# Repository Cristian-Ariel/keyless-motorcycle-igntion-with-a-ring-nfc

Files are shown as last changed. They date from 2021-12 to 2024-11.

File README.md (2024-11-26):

# Keyless Motorcycle Ignition System with a Ring (NFC)
IMAGE ALT TEXT (https://youtu.be/Ip3jwV7dnoM)

The purpose of the system is to enable the ignition of a motorcycle without the use of a physical key, by utilizing an NFC tag (Near Field Communication). A few key features of the system include:
- Zero current consumption when the motorcycle is off, preventing battery discharge.
- The ability to store up to 128 different tags in memory, which are used as keys.
- Access to "Modes" such as Save/Delete Tag Mode and Erase All Tags Mode to prevent unauthorized use.
- A modular hardware design for prototyping and upgrades to accommodate different motorcycle makes and models.

## How do I build one?
Please watch the video on [Youtube](https://youtu.be/Ip3jwV7dnoM) or [Odysee](https://odysee.com/@AsyssComplex:1/keyless.motorcycle.ignition.with.ring:4?r=8kbGTNhCZ6iqTXnwzbdhoQCgzBPm1UvK).
Lastly, make sure to read [the documentation](https://drive.google.com/file/d/1D22VbdVqOc0YWlI75PouFQuNAUfmh6G7/view?usp=sharing). There you will find the materials and tools to build the system as well as several sections where we discuss the working principles of the system more in detail. The rest of the files, code, PCB files, 3D files are located in this repository.

## How do I contribute?
In the second page of the documentation, there is a brief description of how you can do it. Since the whole system is an ongoing project, I will edit this page and the description of the videos for future updates. Don't forget that you can also share your thoughts on the comment section of the videos.

If you find this project useful and would like to support it, you can buy something (shirts, cups, stickers, etc.) on [this store](https://asyss-complex.creator-spring.com) or you can make a donation on [paypal](https://www.paypal.com/paypalme/Cristi4nAriel).

## Enjoy!

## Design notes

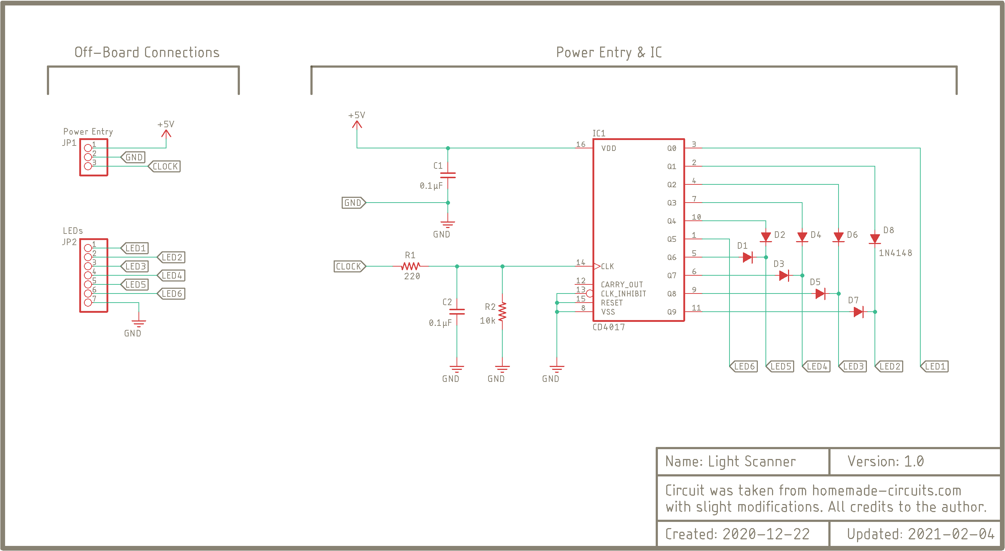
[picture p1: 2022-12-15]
schematic and pcb/light scanner/Light Scanner Capture v1.0.png

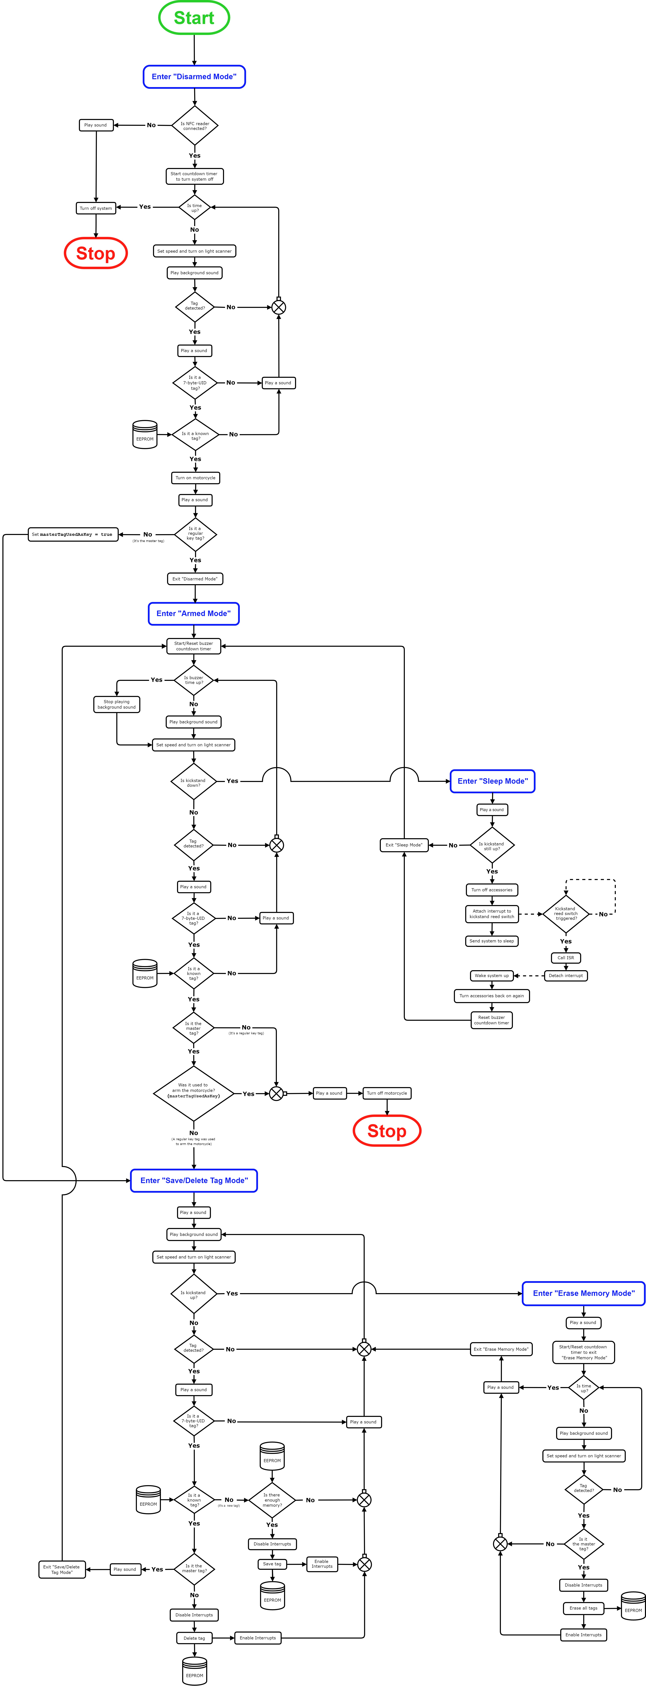
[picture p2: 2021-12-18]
flow chart/flow chart image.jpg

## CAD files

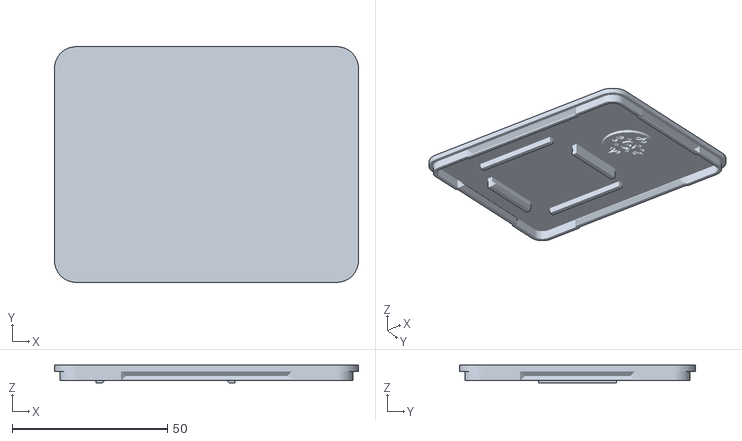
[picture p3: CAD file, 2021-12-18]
3d files/stl files/main enclosure lid.stl
98.0 x 76.0 x 5.70

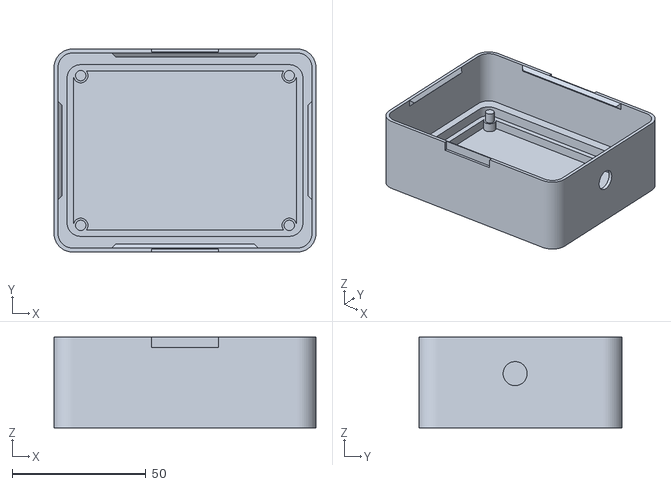
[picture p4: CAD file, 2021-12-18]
3d files/stl files/main enclosure case.stl
98.0 x 76.0 x 34.0

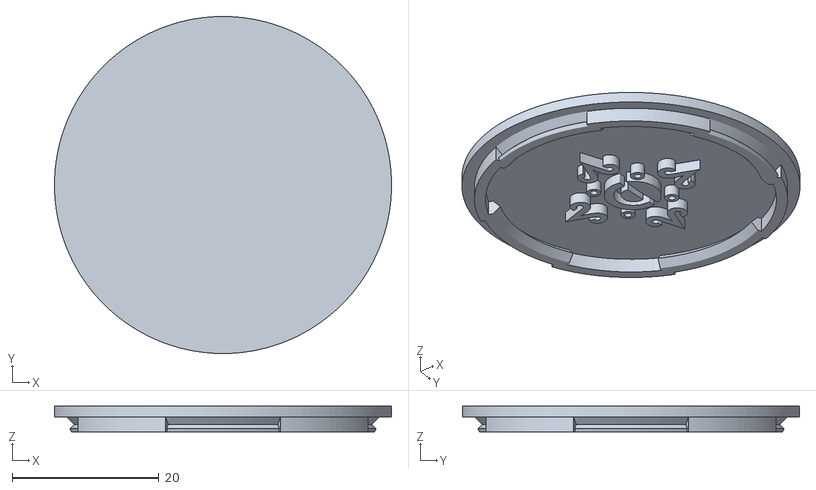
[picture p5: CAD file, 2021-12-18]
3d files/stl files/circular lid.stl
46.0 x 46.0 x 3.50

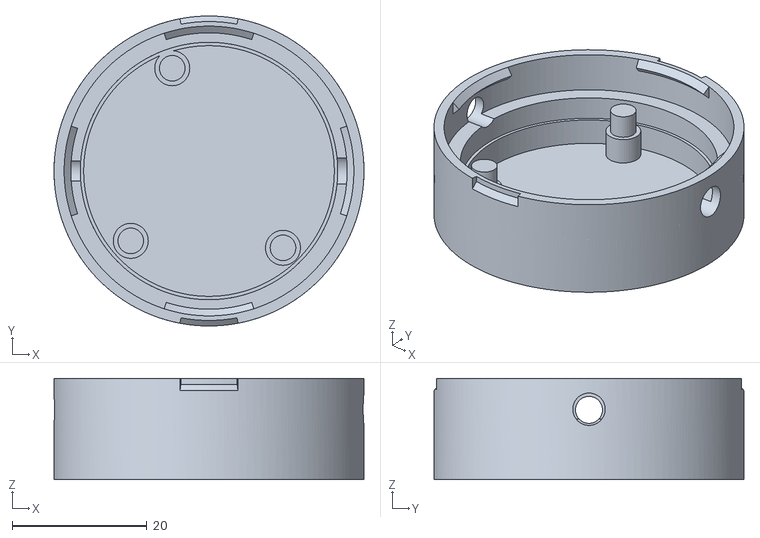
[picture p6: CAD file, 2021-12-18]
3d files/stl files/circular case.stl
46.0 x 46.0 x 15.0

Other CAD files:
3d files/fusion 360 files/circular enclosure v1.0.f3d
3d files/fusion 360 files/main enclosure v1.0.f3d

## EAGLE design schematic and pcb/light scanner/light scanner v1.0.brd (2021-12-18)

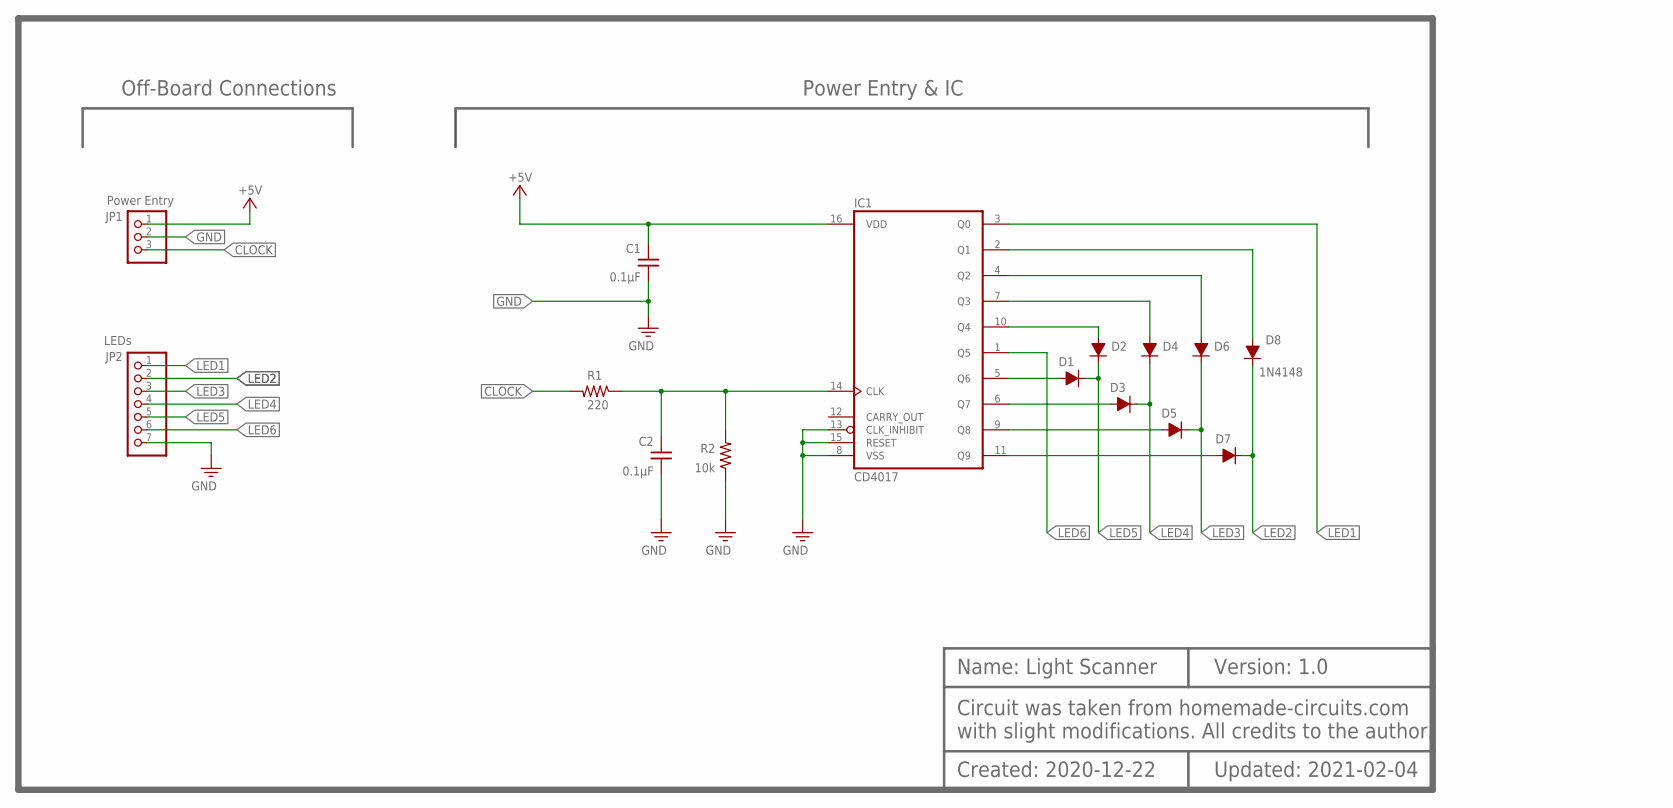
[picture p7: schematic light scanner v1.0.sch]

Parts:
C1, C2: 0.1µF; C_H5
D1, D2, D3, D4, D5, D6, D7: D_1N4148; DO35-7A
D8: 1N4148; DO35-7A
IC1: CD4017; DIP16
JP1: Power Entry; 1X03
JP2: LEDs; 1X07
R1: 220; R_THM
R2: 10k; R_THM

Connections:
+5V: C1.1, IC1.16 (VDD), JP1.1
CLOCK: JP1.3, R1.2
GND: C1.2, C2.2, IC1.8 (VSS), IC1.13 (CLK_INHIBIT), IC1.15 (RESET), JP1.2, JP2.7, R2.1
LED1: IC1.3 (Q0), JP2.1
LED2: D7.C, D8.C, JP2.2
LED3: D5.C, D6.C, JP2.3
LED4: D3.C, D4.C, JP2.4
LED5: D1.C, D2.C, JP2.5
LED6: IC1.1 (Q5), JP2.6
unnamed: C2.1, IC1.14 (CLK), R1.1, R2.2
unnamed: D1.A, IC1.5 (Q6)
unnamed: D2.A, IC1.10 (Q4)
unnamed: D3.A, IC1.6 (Q7)
unnamed: D4.A, IC1.7 (Q3)
unnamed: D5.A, IC1.9 (Q8)
unnamed: D6.A, IC1.4 (Q2)
unnamed: D7.A, IC1.11 (Q9)
unnamed: D8.A, IC1.2 (Q1)

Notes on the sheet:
Power Entry & IC
Off-Board Connections
Name: Light Scanner
Circuit was taken from homemade-circuits.com with slight modifications. All credits to the author.
Created: 2020-12-22
Updated: 2021-02-04
Version: 1.0

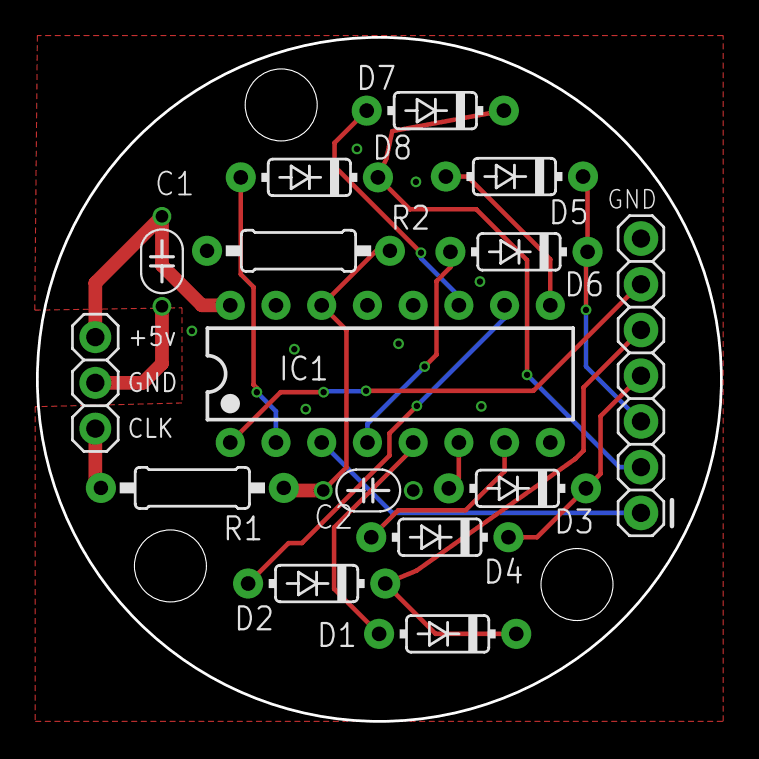
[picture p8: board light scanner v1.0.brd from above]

Board: 2 copper layers, 38.0 x 38.0 mm, 16 parts (1 on the bottom side), 18 nets.

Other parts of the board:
U$2: ASSYS_COMP_LOGO_V6

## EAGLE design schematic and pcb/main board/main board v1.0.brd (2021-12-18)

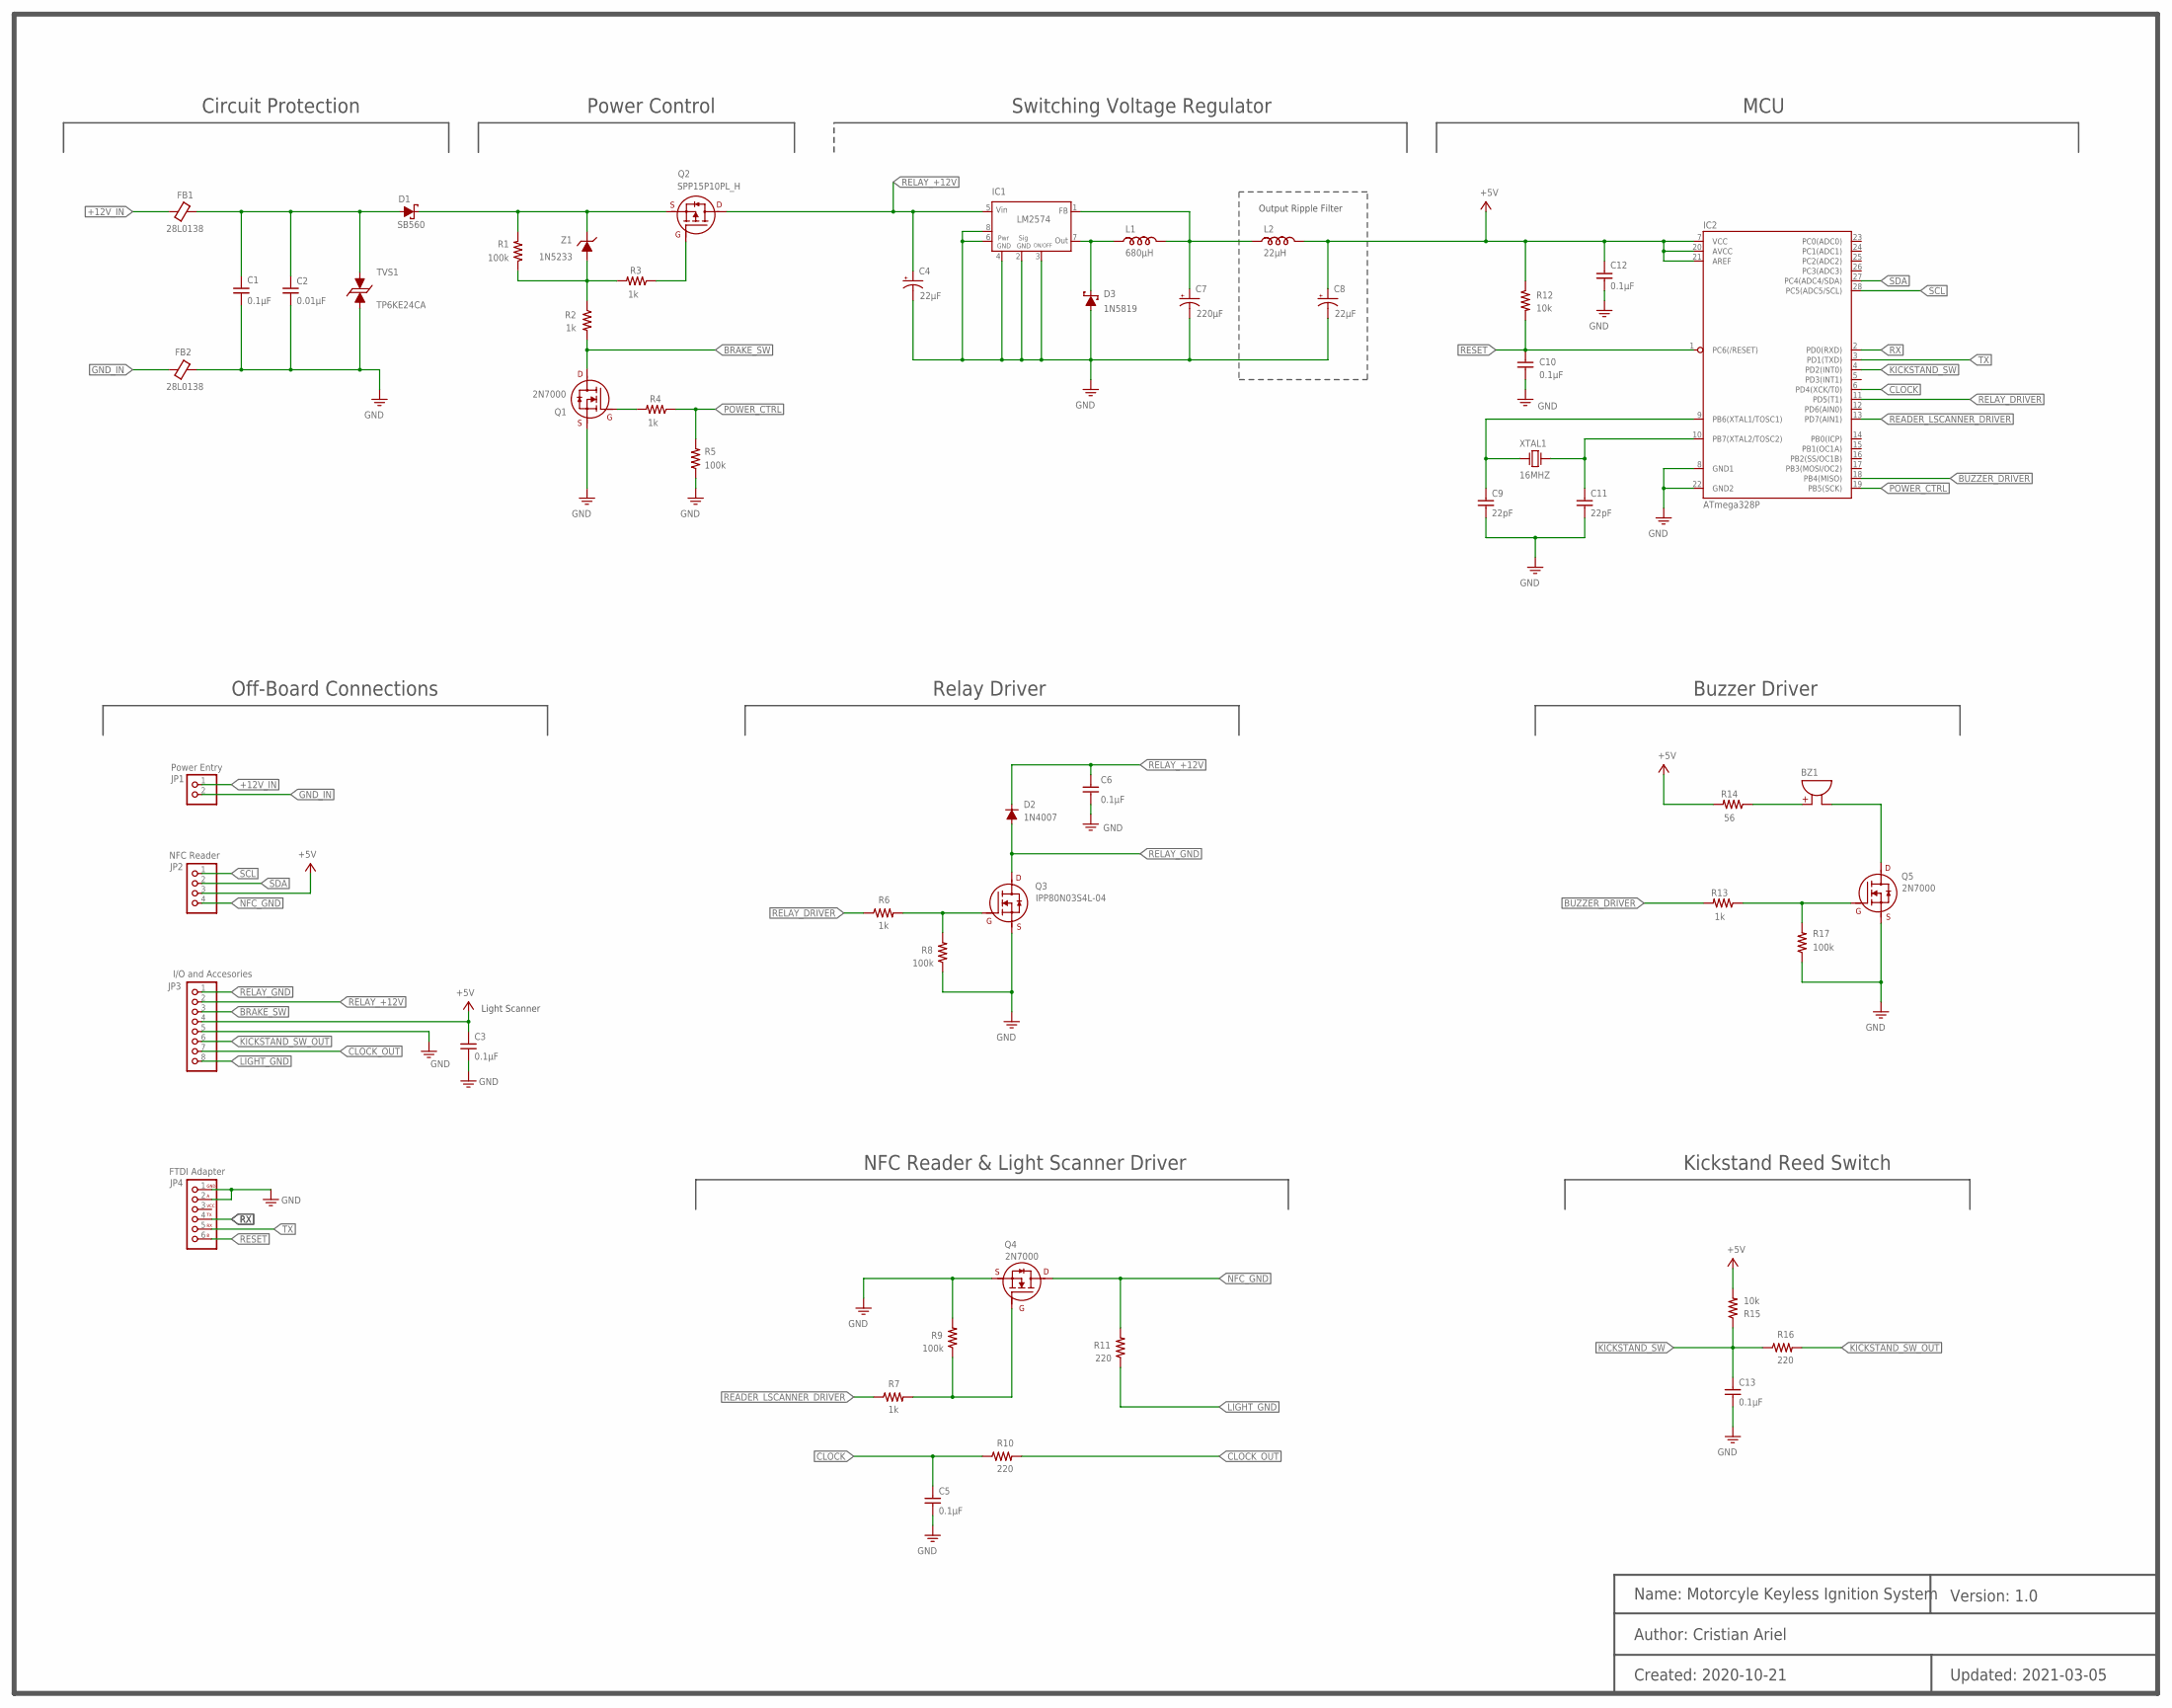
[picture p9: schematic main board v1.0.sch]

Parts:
BZ1: BUZZER_254-EMB15-RO; BUZZER-12
C1, C3, C5, C6, C10, C12, C13: 0.1µF; C_H5
C2: 0.01µF; C_H5
C4, C8: 22µF; C_UBT_8
C7: 220µF; C_UBT_10
C9, C11: 22pF; C_H5
D1: SB560; DO-201AD
D2: 1N4007; DO-41_(DO-204AL)
D3: 1N5819; DO-204AL_(DO-41)
FB1, FB2: 28L0138; FB-5.23
IC1: LM2574; DIL08
IC2: ATmega328P; DIP28
JP1: Power Entry; 1X021
JP2: NFC Reader; KK254_1X4
JP3: I/O and Accesories; 1X08
JP4: FTDI Adapter; 1X06_FTDI
L1: 680µH; PE-526
L2: 22µH; LTF-D
Q1, Q4, Q5: 2N7000; TO-92
Q2: SPP15P10PL_H; TO220
Q3: IPP80N03S4L-04; TO220
R1, R5, R8, R9, R17: 100k; R_THM
R2, R3, R4, R6, R7, R13: 1k; R_THM
R10, R11, R16: 220; R_THM
R12, R15: 10k; R_THM
R14: 56; R_THM
TVS1: TP6KE24CA; DO-204AC_(DO-15)
XTAL1: 16MHZ; HC-49USX
Z1: 1N5233; DO35-7A_ZENER

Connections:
+5V: C3.1, C8.+, C12.1, IC2.7 (VCC), IC2.20 (AVCC), IC2.21 (AREF), JP2.3, JP3.4, L2.1 (END), R12.1, R14.2, R15.2
+12V_IN: FB1.1, JP1.1
BRAKE_SW: JP3.3, Q1.3 (D), R2.2
BUZZER_DRIVER: IC2.18 (PB4(MISO)), R13.2
CLOCK: C5.1, IC2.6 (PD4(XCK/T0)), R10.1
CLOCK_OUT: JP3.7, R10.2
GND: C1.2, C2.2, C3.2, C4.-, C5.2, C6.2, C7.-, C8.-, C9.2, C10.2, C11.2, C12.2, C13.2, D3.A, FB2.2, IC1.2 (SIG_GND), IC1.3 (ON/OFF), IC1.4 (PWR_GND), IC1.6, IC1.8, IC2.8 (GND1), IC2.22 (GND2), JP3.5, JP4.1, JP4.2, Q1.1 (S), Q3.3 (S), Q4.1 (S), Q5.1 (S), R5.1, R8.1, R9.2, R17.1, TVS1.2
GND_IN: FB2.1, JP1.2
KICKSTAND_SW: C13.1, IC2.4 (PD2(INT0)), R15.1, R16.1
KICKSTAND_SW_OUT: JP3.6, R16.2
LIGHT_GND: JP3.8, R11.1
unnamed: BZ1.+, R14.1
unnamed: Q1.2 (G), R4.2
unnamed: D1.C, Q2.3 (S), R1.2, Z1.C
unnamed: Q2.1 (G), R3.1
unnamed: R1.1, R2.1, R3.2, Z1.A
unnamed: C9.1, IC2.9 (PB6(XTAL1/TOSC1)), XTAL1.1
unnamed: Q5.2 (G), R13.1, R17.2
unnamed: D3.C, IC1.7 (OUT), L1.1 (START)
unnamed: C7.+, IC1.1 (FB), L1.2 (END), L2.2 (START)
unnamed: C11.1, IC2.10 (PB7(XTAL2/TOSC2)), XTAL1.2
unnamed: Q3.1 (G), R6.2, R8.2
unnamed: Q4.2 (G), R7.2, R9.1
unnamed: BZ1.-, Q5.3 (D)
unnamed: C1.1, C2.1, D1.A, FB1.2, TVS1.1
NFC_GND: JP2.4, Q4.3 (D), R11.2
POWER_CTRL: IC2.19 (PB5(SCK)), R4.1, R5.2
READER_LSCANNER_DRIVER: IC2.13 (PD7(AIN1)), R7.1
RELAY_+12V: C4.+, C6.1, D2.C, IC1.5 (VIN), JP3.2, Q2.2 (D)
RELAY_DRIVER: IC2.11 (PD5(T1)), R6.1
RELAY_GND: D2.A, JP3.1, Q3.2 (D)
RESET: C10.1, IC2.1 (PC6(/RESET)), JP4.6, R12.2
RX: IC2.2 (PD0(RXD)), JP4.4
SCL: IC2.28 (PC5(ADC5/SCL)), JP2.1
SDA: IC2.27 (PC4(ADC4/SDA)), JP2.2
TX: IC2.3 (PD1(TXD)), JP4.5

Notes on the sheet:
Power Control
Circuit Protection
Switching Voltage Regulator
MCU
Off-Board Connections
Relay Driver
Buzzer Driver
NFC Reader & Light Scanner Driver
Output Ripple Filter
Kickstand Reed Switch
Name: Motorcyle Keyless Ignition System
Author: Cristian Ariel
Version: 1.0
Created: 2020-10-21
Updated: 2021-03-05
Light Scanner

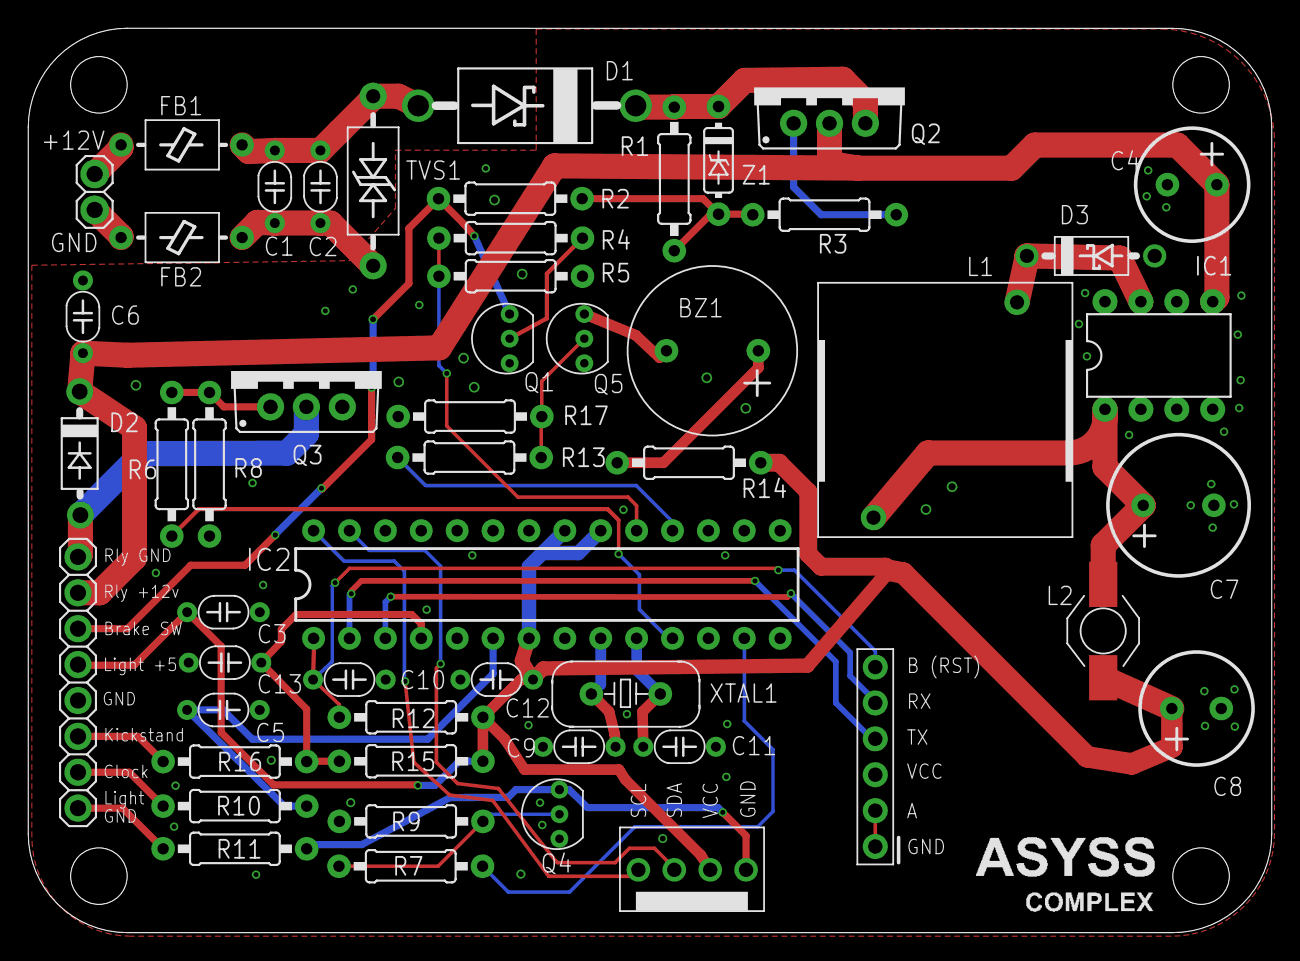
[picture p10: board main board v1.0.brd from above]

Board: 2 copper layers, 88.0 x 64.0 mm, 54 parts (1 on the bottom side), 36 nets.

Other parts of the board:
U$1: ASSYS_COMP_LOGO_V5
U$2: ASSYS_COMP_LOGO_V6

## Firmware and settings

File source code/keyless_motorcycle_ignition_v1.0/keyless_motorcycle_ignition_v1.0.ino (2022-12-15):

/*******************************************************************************
Program name: Keyless Motorcycle Ignition with a Ring (NFC)

Version: 1.0
Author: Cristian Ariel
Created: 2020-07-07
********************************************************************************/

#include <EEPROM.h>
#include <avr/sleep.h>
#include <Wire.h>
#include "soundsList.h" // File is in same directory as main source code

// Libraries for the NFC module
#include <PN532_I2C.h>
#include <PN532.h>
#include <NfcAdapter.h>

// Coment out next line to remove serial monitor commands
//#define DEBUG 
#ifdef DEBUG 
  #define DEBUG_PRINT(x) Serial.print(x)
  #define DEBUG_PRINTLN(x) Serial.println(x)
#else 
  #define DEBUG_PRINT(x)
  #define DEBUG_PRINTLN(x)
#endif

// Set pins to connect over I2C, SDA (pin 27) and SCL (pin 28)
PN532_I2C pn532i2c(Wire);  
PN532 nfcReader(pn532i2c); 

// Intialize pins as labeled on the Arduino Uno board
const byte KICKSTAND_SW        = 2;  // Connected to interrupt-capable pin
const byte CLOCK_PIN           = 4;  // To pin 15 of CD4017
const byte RELAY_DRIVER        = 5;  // To N-channel MOSFET driving relay controlling ignition switch
const byte READR_LIGHTSC_DRIVR = 7;  // To N-channel MOSFET
const byte BUZZER_PIN          = 12; // To N-channel MOSFET
const byte POWER_PIN           = 13; // To N-channel MOSFET driving P-channel MOSFET to turn on/off system

// Initialize global variables
byte scannedTagUid[] = {0 ,0 ,0 ,0 ,0 ,0 ,0 }; // Stores returned UID number from NFC reader
byte tagUidLength    = 0;                      // It can be 4 or 7 bytes depending on card type
const byte MASTER_TAG_UID[] = {0, 0, 0, 0, 0, 0, 0}; // Replace it with your tag UID
const byte MAX_NUM_TAGS     = 5; // Max number of tags that can be stored into EEPROM, limit is 128
int tagExistsFlagAddress    = 0; // Updated by VerifyRegularKeyTagMatchAndGetTagExistsFlagAddress() 
                                 // and used by DeleteTagFromEeprom()
bool masterTagUsedAsKey     = false;

// Timing variables in milliseconds
const unsigned int DISARMED_MODE_MAX_ACTIVE_TIME = 15000; // Time system stays on in Disarmed Mode
const unsigned int BUZZER_ARM_MD_MAX_ACTIVE_TIME = 10000; // Time background sound will play in Armed Mode
const unsigned int ERASE_MEMORY_MAX_ACTIVE_TIME  = 15000; 

// Timing variables for the reset functions
unsigned long eraseMemoryModeStartTime          = 0;
unsigned long bckgrndSoundDisarmedModeStartTime = 0;

// Ligth scanner speed options, ordered from slowest to fastest
const int ARMED_MODE_LGHT_S     = 75;
const int DISSARMED_MODE_LGHT_S = 30;  
const int SAV_DEL_MODE_LGHT_S   = 26;  // Save/Delete Tag Mode
const int ERASE_MEM_LGHT_S      = 10;  // Erase Memory Mode


/*******************************************************************************
*  Setup Function: runs only once                                              *
*******************************************************************************/
void setup () 
{
  pinMode(KICKSTAND_SW, INPUT);
  pinMode(CLOCK_PIN , OUTPUT);  
  pinMode(BUZZER_PIN, OUTPUT);
  pinMode(POWER_PIN, OUTPUT);  
  pinMode(RELAY_DRIVER, OUTPUT);
  pinMode(READR_LIGHTSC_DRIVR, OUTPUT);

  // Set pin states
  digitalWrite(RELAY_DRIVER, LOW);         // Keep MOSFET off
  digitalWrite(POWER_PIN, HIGH);           // Turn on MOSFET to keep system on
  digitalWrite(READR_LIGHTSC_DRIVR, HIGH); // Turn on MOSFET 

  #ifdef DEBUG
  Serial.begin(9600); // Set baud rate
  Serial.println("Keyless Motorcycle Ignition System");
  #endif                        
}

/*******************************************************************************
*  Loop Function: runs on forever                                              *
*******************************************************************************/
void loop ()
{ 
  DEBUG_PRINTLN("====================== Entering DISARMED MODE ======================");
 
  DisarmedMode();
  ArmedMode();
} 


enum SoundsNameList
{
  // Enumerators are converted automatically into constant integers
  // This enumeration contains the NAME of every sound used by PlaySound() 

  // Background sounds are played while we are in a specific "Mode"
  //
  ARMED_MODE_SOUND    = 1, // Slow
  DISARMED_MODE_SOUND = 2, // Normal
  SAV_DEL_MODE_SOUND  = 3, // Fast
  ERASE_MEM_SOUND     = 4, // Extra fast 

  TAG_SCANNED   = 5,  // Play every time we scan any tag 
  ACCEPTED_TAG  = 6,  // "" if either regular key tag or the master tag is scanned.
                      //    It's also played when turning off motorcycle
  UNKNOWN_TAG   = 7,  // "" if either the tag is invalid (UID != 7) or unknown

  ENTER_SAV_DEL_MODE   = 8,  // Play when master tag is scanned
  EXIT_SAV_DEL_MODE    = 9,  // "" when master tag is scanned
  ENTER_ERASE_MEM_MODE = 10, // "" when brake pedal is pressed 
  EXIT_ERASE_MEM_MODE  = 11, 
  ENTER_SLEEP_MODE     = 12, // "" when kickstand switch is pressed

  TAG_SAVED        = 13, // Play when new tag is scanned
  TAG_DELETED      = 14, // "" when known tag is scanned
  MEM_ERASED       = 15, // "" when the master tag is scanned 
  MEMORY_FULL      = 16, // "" when we've reached the limit (MAX_NUM_TAGS)
  READER_NOT_FOUND = 17  // "" when reader is disconnected/offline
};

/*******************************************************************************
* DISARMED MODE: motorcycle system is off                                      *
*******************************************************************************/
void DisarmedMode ()
{
  NfcReaderConnectionHandler();

  while (true) { // Infinite loop
    DisarmedModeCountdownHandler(DISARMED_MODE_MAX_ACTIVE_TIME); // Check if it's time to turn system off
    SetSpeedAndTurnOnLightScanner(DISSARMED_MODE_LGHT_S);
    PlaySound(DISARMED_MODE_SOUND);
        
    bool tagFound = nfcReader.readPassiveTargetID(PN532_MIFARE_ISO14443A, &scannedTagUid[0], &tagUidLength);
    if (tagFound == true) {             
      PlaySound(TAG_SCANNED); // Everytime a tag is scanned

      #ifdef DEBUG
      PrintTagUid(scannedTagUid); 
      #endif

      if (tagUidLength == 7) {
        bool regularKeyTagWasScanned  = VerifyRegularKeyTagMatchAndGetTagExistsFlagAddress(scannedTagUid); 
        bool masterTagWasScanned = VerifyMasterTagMatch(scannedTagUid, MASTER_TAG_UID); 
        if (regularKeyTagWasScanned || masterTagWasScanned) { // known tag?
          digitalWrite(RELAY_DRIVER, HIGH); // Access has been granted, turn on motorycle!
          PlaySound(ACCEPTED_TAG); 
          
          // Check which kind of known tag we have
          if (regularKeyTagWasScanned == true) {
            DEBUG_PRINTLN("  =  Regular key tag scanned!!");
            return; // Go back to loop function and enter Armed Mode
          }
          else if (masterTagWasScanned == true) {
            DEBUG_PRINTLN("  =   This is the master tag!!");
            masterTagUsedAsKey = true;
            SaveDeleteTagMode();
            return; // Go back to loop function and enter Armed Mode
          }          
        }
        else {
          DEBUG_PRINTLN("  =  Unknown tag scanned!!");
          PlaySound(UNKNOWN_TAG);
        }
      } // End of if (tagUIDLenght == 7)
      else {
        DEBUG_PRINTLN("  =  Tag UID not supported!!"); 
        PlaySound(UNKNOWN_TAG);
      }

      DEBUG_PRINTLN("\nWaiting for a tag...\n");
      delay(600); // Wait a little before continuing, otherswise we will keep calling the functions
    } // End of if(tagFound)
  } // End of while(true)

}

void NfcReaderConnectionHandler ()
{
 // Check that reader is connected, if there is communication set up reader 
 // and continue normal program flow, otherwise turn off MCU.

  nfcReader.begin(); // Initialize communication with the reader module
  bool readerIsConnected = nfcReader.getFirmwareVersion(); // See if reader responds by requesting some info
  if (readerIsConnected == true) { 
    DEBUG_PRINTLN("Reader Found!!\n");
    DEBUG_PRINTLN("Waiting for a tag... \n");
  /*
    Set the max number of retry attempts to read from a card. 
    This prevents us from waiting forever for a card, which is the default behaviour 
    of the PN532. 0xFF to wait forever, 0x00..0xFE to timeout after x retries.
  */
    nfcReader.setPassiveActivationRetries(0x01); 
    nfcReader.SAMConfig(); // Configures board to read RFID tags 
  }
  else {
    DEBUG_PRINTLN("Reader Not Found!!\n");
    DEBUG_PRINTLN("SYSTEM OFF!!!");

    PlaySound(READER_NOT_FOUND);
    while (true) { // Endless loop
    digitalWrite(POWER_PIN, LOW); // Turn off MCU
    }
  }

}

void PlaySound (const int SOUND_NAME)
{   
  static unsigned long previousTimeTone = 0;    
  unsigned long currentTimeInMillis = millis(); // Counter module built-in into the MCU
  unsigned long timeElapsed = (currentTimeInMillis - previousTimeTone);

  // Note that each case label needs to be a constant
  //
  switch (SOUND_NAME)
  {
  case ARMED_MODE_SOUND:
    if (timeElapsed >= 2000) { // Computes the delay. Set speed by changing value on the right
      tone(BUZZER_PIN, 1600, 84);
      previousTimeTone = currentTimeInMillis; // Update the time for the next time around
    } 
    break;

  case DISARMED_MODE_SOUND:
    if (timeElapsed >= 900) {
      tone(BUZZER_PIN, 1220, 84);
      previousTimeTone = currentTimeInMillis; 
    }
    break;

  case SAV_DEL_MODE_SOUND:
    if (timeElapsed >= 800) {
      tone(BUZZER_PIN, 1220, 84);
      previousTimeTone = currentTimeInMillis; 
    }
    break;

  case ERASE_MEM_SOUND:
    if (timeElapsed >= 300) {
      tone(BUZZER_PIN, 130, 95);
      previousTimeTone = currentTimeInMillis; 
    }
    break;

  case TAG_SCANNED:
    PlayPreTone(BUZZER_PIN);
    break;

  case ACCEPTED_TAG: 
    PlayAcceptedTag(BUZZER_PIN);
    break;

  case UNKNOWN_TAG:
    PlayUnknwownTag(BUZZER_PIN);
    break;

  case ENTER_SAV_DEL_MODE:
    PlayEnterSaveDeleteTagMode(BUZZER_PIN);
    break;

  case EXIT_SAV_DEL_MODE:
    PlayExitSaveDeleteTagMode(BUZZER_PIN);
    break;

  case ENTER_ERASE_MEM_MODE:
    PlayEnterEraseMemoryMode(BUZZER_PIN);
    break;

  case EXIT_ERASE_MEM_MODE:
    PlayExitEraseMemoryMode(BUZZER_PIN);
    break;
  
  case ENTER_SLEEP_MODE:
    PlayEnterSleepMode(BUZZER_PIN);
    break;

  case TAG_SAVED:
    PlayTagSaved(BUZZER_PIN);
    break;

  case TAG_DELETED:
    PlayTagDeleted(BUZZER_PIN);
    break;

  case MEM_ERASED:
    PlayMemoryErased(BUZZER_PIN);
    break;

  case MEMORY_FULL:
    PlayMemoryFull(BUZZER_PIN); 
    break; 

  case READER_NOT_FOUND:
    PlayReaderNotFound(BUZZER_PIN);
    break;
  }
}

void DisarmedModeCountdownHandler (const unsigned int MAX_ACTIVE_TIME)
{
  // Make sure we record the starting time ONLY once, when first entering this function
  static unsigned long disarmedModeStartTime = 0;
  static bool startTimeWasRecorded = false;
  if (startTimeWasRecorded == false) {
    disarmedModeStartTime = millis(); // Updade it to current time
    startTimeWasRecorded = true;      // Toggle flag, so we record starting time once
  }

  // Check if it's time to turn off system while in Disarmed Mode 
  unsigned long disarmedModeElapsedTime = (millis() - disarmedModeStartTime); // Update time frequenly
  if (disarmedModeElapsedTime >= MAX_ACTIVE_TIME) { // See if time's up
    DEBUG_PRINTLN("SYSTEM OFF!!!");
    
    disarmedModeStartTime = false; // This not necessary. It's just for debbuging so before turning  
                                   // system off, reset variable for the next time we enter Disarmed Mode
    while (true) {
    digitalWrite(POWER_PIN, LOW);  // Turn off MCU
    }
  }

}

void SetSpeedAndTurnOnLightScanner (const unsigned int CLOCK_SPEED)
{
  static bool clockPolarity = LOW; // Sets clock pin of CD4017 either LOW or HIGH                         
  static unsigned long previousTimeClock = 0; // Tracks the number of seconds that have passed by using the timer 
  unsigned long timeElapsed = (millis() - previousTimeClock); // millis() is a counter module built-in into the MCU 
  if (timeElapsed >= CLOCK_SPEED) {         // Computes the 'delay'
    clockPolarity = !clockPolarity;         // Toggle clock signal variable
    previousTimeClock = millis();           // Update time for the next time around
    digitalWrite(CLOCK_PIN, clockPolarity); // Toggle clock signal pin
  }

} 

bool VerifyRegularKeyTagMatchAndGetTagExistsFlagAddress (byte scannedTagUid[])
{ 
  // Check if scanned tag was saved to EEPROM, if so, get its address 
  // Loop through all the tags. If tag found, loop to see if there is a match, if so, get flag address

  // Values of the 1st tag to start reading from
  int tagExistsFlagTempAddr = 0; // 1s byte address preceding each tag's full UID address. Update it each time through the loop
  int tagAddressIndex       = 1; // This is always the address right after the tagExistsFlagAddress
  int lastTagAddressIndex   = 7; // Holds tag's last UID byte address 

  for (byte i = 0; i < MAX_NUM_TAGS; i++) { // Loop through all the max number of tags    
    bool tagExistsFlag = EEPROM.read(tagExistsFlagTempAddr); // Read 1st byte preceding each tag UID address
    if (tagExistsFlag == true) { // Tag found, now make sure it's a match 
      byte uidArrayIndex      = 0;                               
      byte tagUidMatchCounter = 0;  // Keep track of the bytes that have matched our scanned tag.
      for (tagAddressIndex; tagAddressIndex <= lastTagAddressIndex; tagAddressIndex++, uidArrayIndex++) { // Loop through the UID number            
        if (scannedTagUid[uidArrayIndex] == EEPROM.read(tagAddressIndex)) { // Read EERPOM and look for an UID byte match
          tagUidMatchCounter++;   // Update counter
          if (tagUidMatchCounter == 7) { // If all bytes have matched, it's a regular key tag! 
            tagExistsFlagAddress = tagExistsFlagTempAddr; // Get EEPROM address of scanned tag (it's saved in a global variable)
                                                          // This variable is ONLY used as argument for DeleteTagFromEeprom()
            return true; // Regular key tag found, stop looping and exit function
          }
        }
        else { // At the 1st mistmach break current loop, and go read the next tag in EERPOM
          break;  
        }
      } // End of for (tagAddressIndex...
    } // End of if(tagExistsFlag... 

    // Update variables if no tag was found or if there is a mismatch, so that we're ready to read next tag
    tagExistsFlagTempAddr += 8;            // This is the next tagExistsFlagAddress
    // For the loops
    tagAddressIndex = tagExistsFlagTempAddr + 1; 
    lastTagAddressIndex  = tagExistsFlagTempAddr + 7;  
  } // End of for loop
  return false; // Unknown tag! Exit function

}

bool VerifyMasterTagMatch (byte scannedTagUid[], const byte MASTER_TAG_UID[]) 
{
  byte tagUidMatchCounter = 0; 
  for (byte i = 0; i < 7; i++) { // Loop through the UID number
    if (scannedTagUid[i] == MASTER_TAG_UID[i]) { // Look for a match
      tagUidMatchCounter++; 
      if (tagUidMatchCounter == 7) {
        return true;   // All bytes have matched, we got the master tag!
      }
    }    
  }
  return false; // Break function as soon as a mismatch is found

} 

/*******************************************************************************
* SAVE & DELETE TAG MODE: master tag was scanned                               *
*******************************************************************************/
void SaveDeleteTagMode () 
{
  #ifdef DEBUG
  DEBUG_PRINTLN("\n====================== Entering SAVE/DELETE TAG MODE ===============");
  PrintTagsSavedCounter();  
  PrintEepromContent();
  DEBUG_PRINTLN("\nPlease scan tag to add or delete...\n");  
  #endif

  PlaySound(ENTER_SAV_DEL_MODE);
  delay(1000); // Since we just scanned the master tag wait a little, otherwise will break the infinte loop 

  while (true) { // Infinite loop to scan a tag    
    PlaySound(SAV_DEL_MODE_SOUND);  
    SetSpeedAndTurnOnLightScanner(SAV_DEL_MODE_LGHT_S); 
    EnterEraseMemoryModeHadler(); // Check kickstand and enter Erase Memory Mode if it's up
        
    // Reset variable and scan again
    bool tagFound = nfcReader.readPassiveTargetID(PN532_MIFARE_ISO14443A, &scannedTagUid[0], &tagUidLength);  
    if (tagFound == true) {
       PlaySound(TAG_SCANNED);  // Everytime a tag is scanned

      #ifdef DEBUG
      PrintTagUid(scannedTagUid); 
      #endif
      
      if (tagUidLength == 7) { // Identify the type of tag
        bool regularKeyTagWasScanned  = VerifyRegularKeyTagMatchAndGetTagExistsFlagAddress(scannedTagUid); 
        bool masterTagWasScanned = VerifyMasterTagMatch(scannedTagUid, MASTER_TAG_UID);
        // Valid tag, now decide what to do with it...

        if (regularKeyTagWasScanned == false && masterTagWasScanned == false) { // It's a new tag, save it!
          bool eepromIsFull = CheckAvailableEepromSpace(); // But make sure we have enough space to save it first
          if (eepromIsFull == false) { 
              SaveTagToEeprom(UpdateAddrToWriteInto(), scannedTagUid); // Enough memory available, save it!
              PlaySound(TAG_SAVED);
          }
          else if (eepromIsFull == true){ 
            PlaySound(MEMORY_FULL);
            DEBUG_PRINT("\n");
            DEBUG_PRINT("\n____________ Memory Full!! _____________\n\n");
          } 
        }
        else if (masterTagWasScanned == true) { // Exit current mode
          PlaySound(EXIT_SAV_DEL_MODE);
          DEBUG_PRINTLN("  =   This is the master tag!!\n");
          DEBUG_PRINTLN("Exiting Save/Delete tag mode!");

          return; // Break infinite while loop and go back to Armed Mode
        }        
        else if (regularKeyTagWasScanned == true) { // Delete tag!
          DeleteTagFromEeprom(tagExistsFlagAddress); 
          PlaySound(TAG_DELETED);   
        }

        #ifdef DEBUG
        // Print some info after deleting/saving a tag
        PrintTagsSavedCounter();
        PrintEepromContent();
        #endif
      }
      else { // Tag not supported (UID != 7)
        DEBUG_PRINTLN("  = Tag UID not supported!!\n"); 
        PlaySound(UNKNOWN_TAG);
      }
      //delay(800); // We already added a small delay when playing a sound so add another delay if 
                    // you prefer so we don't add the same tag right after erasing it, if applicable.
    } // End of if(tagFound)
  } // End of infinite while loop

}

void EnterEraseMemoryModeHadler ()
{
  // Reads the state of the brake reed switch to enter Erase Memory Mode 

  bool kickstandSwitchPressed = !digitalRead(KICKSTAND_SW); // Pin is normally high, so change it normally low
  if (kickstandSwitchPressed == true) {
    DEBUG_PRINTLN("Entering Erase Memory Mode\n");
    EraseMemoryMode();
  }

}

/*******************************************************************************
* ERASE MEMORY MODE: kickstand reed switch triggered in Save/Delete Tag Mode   *
*******************************************************************************/
void EraseMemoryMode ()
{
  #ifdef DEBUG
  DEBUG_PRINTLN("\n====================== Entering ERASE MEMORY MODE ===============");
  PrintTagsSavedCounter();
  PrintEepromContent();
  DEBUG_PRINTLN("Please re-scan the master tag to erase all tags from EEPROM");
  DEBUG_PRINTLN("or scan any other tag to exit...\n");
  #endif

  PlaySound(ENTER_ERASE_MEM_MODE);
  ResetEraseMemoryCountdownTimer();

  while (true) { // Infinite loop
    if (IsTimeToExitEraseMemoryMode(ERASE_MEMORY_MAX_ACTIVE_TIME) == true) {
      PlaySound(EXIT_ERASE_MEM_MODE);
      break; // Break current infinite loop to exit function thereafter
    }

    PlaySound(ERASE_MEM_SOUND);
    SetSpeedAndTurnOnLightScanner(ERASE_MEM_LGHT_S);    
    
    bool tagFound = nfcReader.readPassiveTargetID(PN532_MIFARE_ISO14443A, &scannedTagUid[0], &tagUidLength); // Reset variable and scan again  
    if (tagFound == true) {
      PlaySound(TAG_SCANNED); // Everytime any tag is scanned
      bool masterTagWasScanned = VerifyMasterTagMatch(scannedTagUid, MASTER_TAG_UID);
      if (masterTagWasScanned == true) { // Erase tags      
        DEBUG_PRINTLN("Erasing all tags from EEPROM\n");
        EraseMemory(); 
        PlaySound(MEM_ERASED);
        PlaySound(EXIT_ERASE_MEM_MODE);
        DEBUG_PRINTLN("Done!!!\n");        

        #ifdef DEBUG
        // Again print some data before exiting
        PrintTagsSavedCounter();
        PrintEepromContent();
        #endif

        break; // Break current infinite loop to exit function thereafter
      } 
      else { // If a tag other than the master tag was scanned, then exit function        
        DEBUG_PRINTLN("Exiting Erase Memory Mode");

        PlaySound(ACCEPTED_TAG);
        PlaySound(EXIT_ERASE_MEM_MODE);
        delay(500); // Wait while moving tag away to avoid scanning the tag twice
        
        #ifdef DEBUG      
        DEBUG_PRINTLN("\n====================== Entering SAVE/DELETE TAG MODE ===============");
        PrintTagsSavedCounter(); 
        DEBUG_PRINTLN("\nPlease scan tag to add or delete...\n");  
        #endif
       
        break; // Break current infinite loop to exit function thereafter
      }
    } // End of if (tagFound...
  } // End of while loop
  return; // Go back to Save/Delete Tag Mode
}

void ResetEraseMemoryCountdownTimer ()
{
  eraseMemoryModeStartTime = millis(); // Update time
}

bool IsTimeToExitEraseMemoryMode (const unsigned int MAX_ACTIVE_TIME)
{
  // Start countdown timer and check if time's up
  unsigned long eraseMemoryModeElapsedTime = (millis() - eraseMemoryModeStartTime); // Keep updating time
  if (eraseMemoryModeElapsedTime >=  MAX_ACTIVE_TIME) { // See if time is up
    return true; // Time's up!!
  }
  else { 
    return false;
  }
}
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
